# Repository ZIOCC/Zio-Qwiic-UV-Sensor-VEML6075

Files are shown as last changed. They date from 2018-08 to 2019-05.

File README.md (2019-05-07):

# Zio Qwiic UV Sensor (VEML6075)

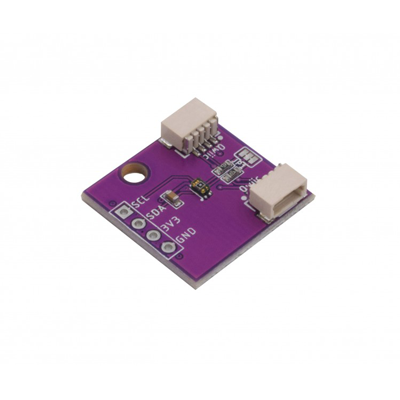
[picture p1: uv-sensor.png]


> This product can be available for purchase [here](https://www.smart-prototyping.com/Zio-Qwiic-UV-Sensor-VEML6075).

> Note: This sensor is referenced from [Sparkfun's Qwiic VEML6075](https://www.sparkfun.com/products/14748) module's PCB design.

#### Description

This Ultraviolet sensor can be used to detect the intensity of UV A and UV B light waves. The VEML6075 by Vishay has a very good conduct on taking measurements even on a long time solar exposure featuring I2C interface.  It can also output the UVI (Ultraviolet Index, the strength of light radiation at a particular place and time) by doing a simple calculation. The values for UVI range from 0 to 11+, which 6 or above indicate a high radiation index - time to use some sunscreen or even stay indoors!

As most of ZIO boards, it incorporates the Qwiic connector to transfer UV data via I2C, just plug and start taking measurements. Check out the code to setup different UV readings. 

This great little sensor can use either I2C or SPI interfaces so we made it pretty accessible to switch to SPI. Simply solder the header pins provided if you want to!

#### Specification

* Supply Voltage: 3.3V
* Peak Sensitivity UV A: 365nm
* Peak Sensitivity UV B: 330nm
* Operation Temperature Range: -40 to 85°C
* Interface: I2C (address 0x10)
* Dimensions: 20.0 x 20.0mm
* Weight: 1.4g

#### Links

* [VEML6075 Datasheet](https://www.vishay.com/docs/84304/veml6075.pdf)
* [Eagle File and Schematic](https://github.com/ZIOCC/Zio-Qwiic-UV-Sensor-VEML6075)
* [VEML6075 Library](https://github.com/adafruit/Adafruit_VEML6075)

> ###### About Zio
> Zio is a new line of open sourced, compact, and grid layout boards, fully integrated for Arduino and Qwiic ecosystem. Designed ideally for wearables, robotics, small-space limitations or other on the go projects. Check out other awesome Zio products [here](https://www.smart-prototyping.com/Zio).

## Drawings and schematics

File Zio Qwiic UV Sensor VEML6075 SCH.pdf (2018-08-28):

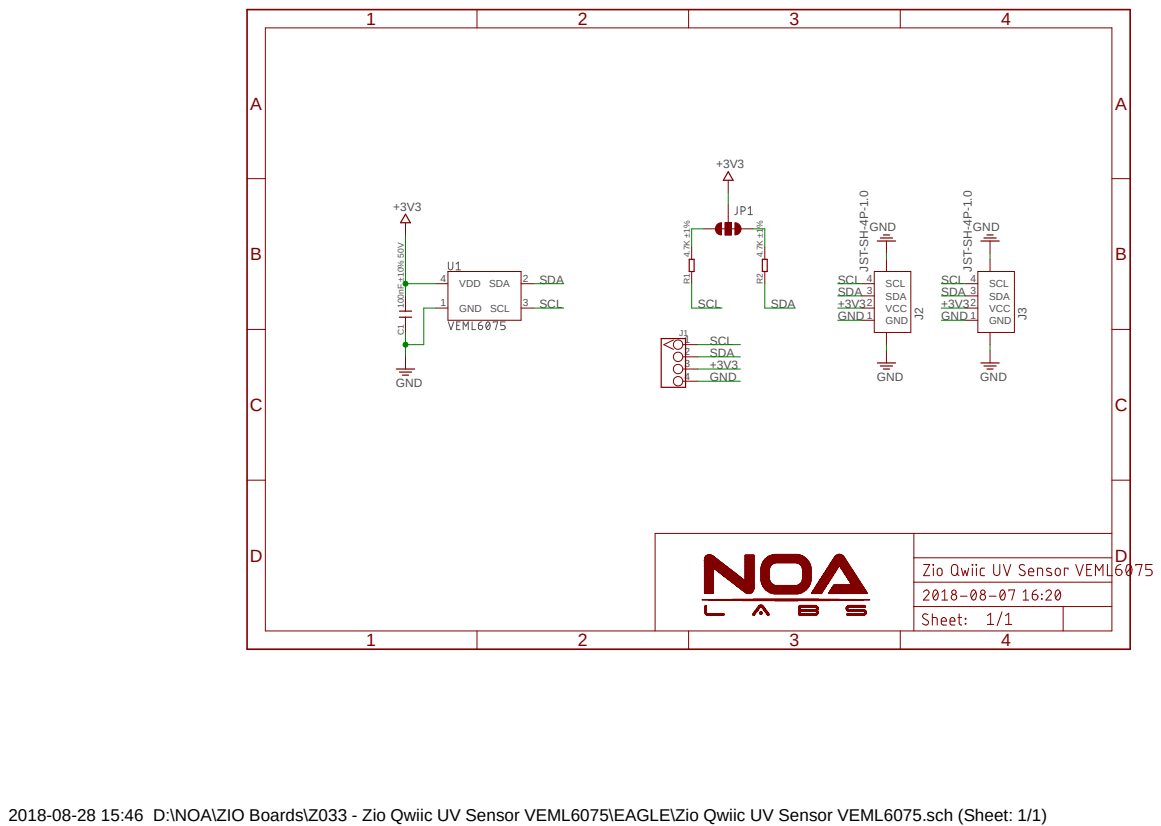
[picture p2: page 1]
GND; GND 4.7K ±1%; 4.7K ±1% 100nF ±10% ⁵⁰V; GND 1; VCC 2; SDA 3; SCL 4; J3 JST⁻SH⁻⁴P⁻¹.0; J2 JST⁻SH⁻⁴P⁻¹.0 R¹; VDD 4; SDA; SCL

2018-08-28 15:46 D:\NOA\ZIO Boards\Z033 - Zio Qwiic UV Sensor VEML6075\EAGLE\Zio Qwiic UV Sensor VEML6075.sch (Sheet: 1/1)

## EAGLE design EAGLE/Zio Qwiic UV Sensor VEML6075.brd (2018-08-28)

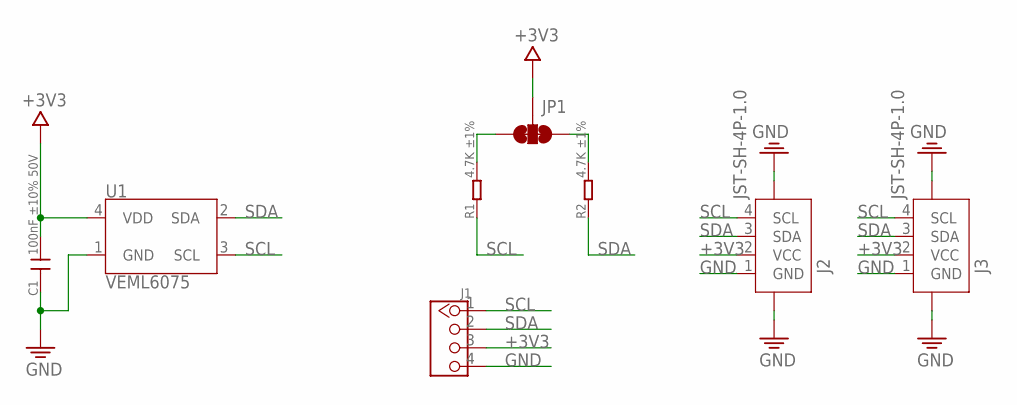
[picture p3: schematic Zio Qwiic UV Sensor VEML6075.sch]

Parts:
C1: 100nF ±10% 50V; C0603
J1: HEADER-4P-60/35MIL; 4P-65/35MIL
J2, J3: JST-SH-4P-1.0; JST-SH-4P
JP1: SMT-JUMPER_3_2-NC_TRACE
R1, R2: 4.7K ±1%; R0603
U1: VEML6075; VEML6075_A3OP

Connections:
+3V3: C1.2, J1.3, J2.2 (VCC), J3.2 (VCC), JP1.2, U1.4 (VDD)
GND: C1.1, J1.4, J2.1 (GND), J2.NC1 (5), J2.NC2 (6), J3.1 (GND), J3.NC1 (5), J3.NC2 (6), U1.1 (GND)
unnamed: JP1.3, R1.2
unnamed: JP1.1, R2.2
SCL: J1.1, J2.4 (SCL), J3.4 (SCL), R1.1, U1.3 (SCL)
SDA: J1.2, J2.3 (SDA), J3.3 (SDA), R2.1, U1.2 (SDA)

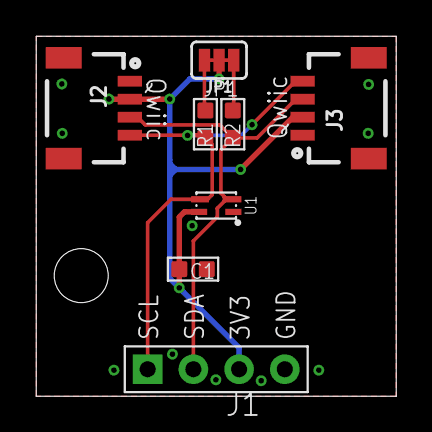
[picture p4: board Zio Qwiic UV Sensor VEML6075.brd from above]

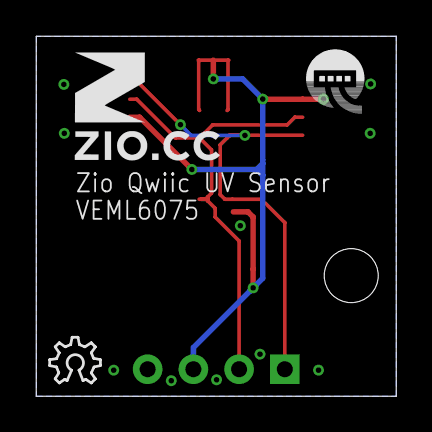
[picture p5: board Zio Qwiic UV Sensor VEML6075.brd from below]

Board: 2 copper layers, 20.0 x 20.0 mm, 11 parts (3 on the bottom side), 6 nets.

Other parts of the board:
U$3: 6MM
U$4: OSHW_6X100_NOTEXT
U$5: QWIIC-LOGO-BASIC
